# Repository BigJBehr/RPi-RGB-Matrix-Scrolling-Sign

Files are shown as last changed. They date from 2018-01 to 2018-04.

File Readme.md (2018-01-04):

# Raspberry Pi RGB LED Matrix Scrolling Sign
This project is for a Raspberry Pi based RGB LED Matrix scrolling sign. A python script running on the Raspberry Pi uses WiFi and your internet connection to collect data from various web sites. The collected data is parsed, formatted and display on the RGB Matrix as scrolling text messages. The sign scrolls; time, date, quote-of-the-day, jokes, local weather, environment data, headlines, birthday greetings and holiday messages. The birthday and holiday greetings are user definable by editing a pair of XML files. Complete instructions on how to build one of these is available on the Instructables web site here; https://www.instructables.com/id/Raspberry-Pi-Scrolling-Sign/.

This is a list of the files found here. All of these files should be in the same directory on your Raspberry Pi.
    RGB-32x64.py    - python script that runs the scrolling display
    options.ini     - configuration file that is used to enable/disable features
    birthdays.xml   - file of birthday messages and dates
    holidays.xml    - file of holiday messages and dates
    samplebase.py   - python script from the Henner Zeller RGB matrix library
    fonts           - fonts directory from the Henner Zeller RGB matrix drive library
    Eagle           - this folder contains the Eagle files required to make your own boards

The Henner Zeller RGB matrix library should also be in this directory. You can get the library here; https://github.com/hzeller/rpi-rgb-led-matrix

## The Eagle folder has a zip file that has what is needed to send to a board manufacturer to make boards for you. It also has the Eagle schematic and board layout files and a PDF of the schematic.

Enjoy

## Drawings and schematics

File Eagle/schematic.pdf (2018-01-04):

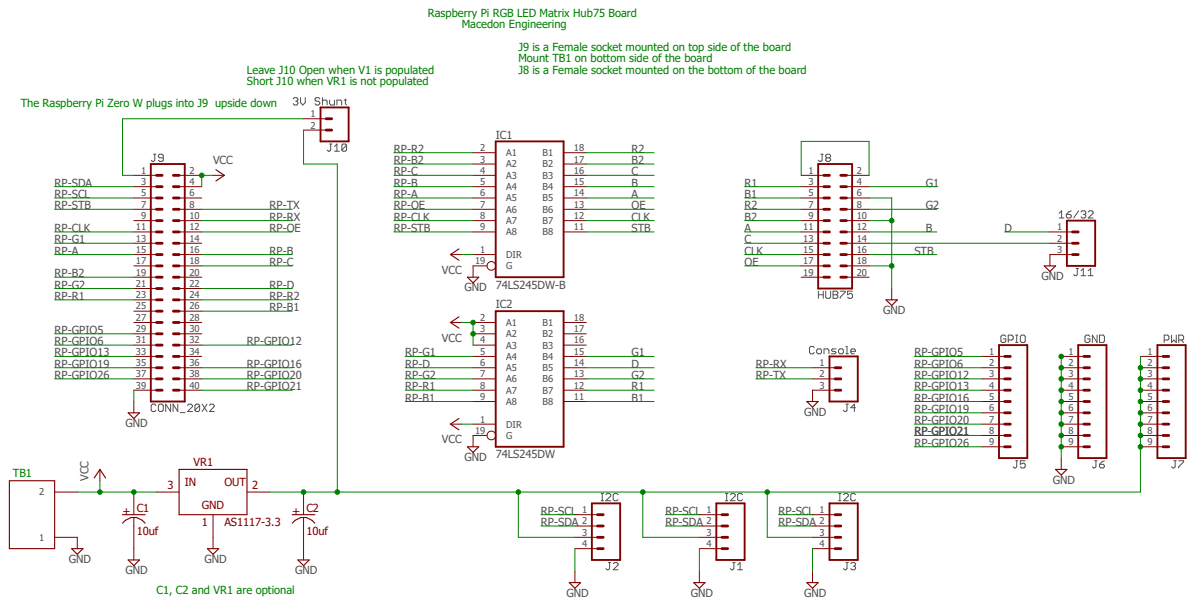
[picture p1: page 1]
GND; VCC; IC2DIR 1; IC1DIR 1; CLK; STB; RP-GPIO12; RP-GPIO16; RP-GPIO20; RP-GPIO21; RP-SDA; RP-SCL; RP-CLK; RP-STB; RP-GPIO5; RP-GPIO6; RP-GPIO13; RP-GPIO19; RP-GPIO26; OUT

Raspberry Pi RGB LED Matrix Hub75 Board
Macedon Engineering
VCC
RP-SDA
RP-SCL
RP-STB

J9 is a Female socket mounted on top side of the board
Mount TB1 on bottom side of the board
J8 is a Female socket mounted on the bottom of the board

Leave J10 Open when V1 is populated
Short J10 when VR1 is not populated

The Raspberry Pi Zero W plugs into J9 upside down

GND
C1, C2 and VR1 are optional

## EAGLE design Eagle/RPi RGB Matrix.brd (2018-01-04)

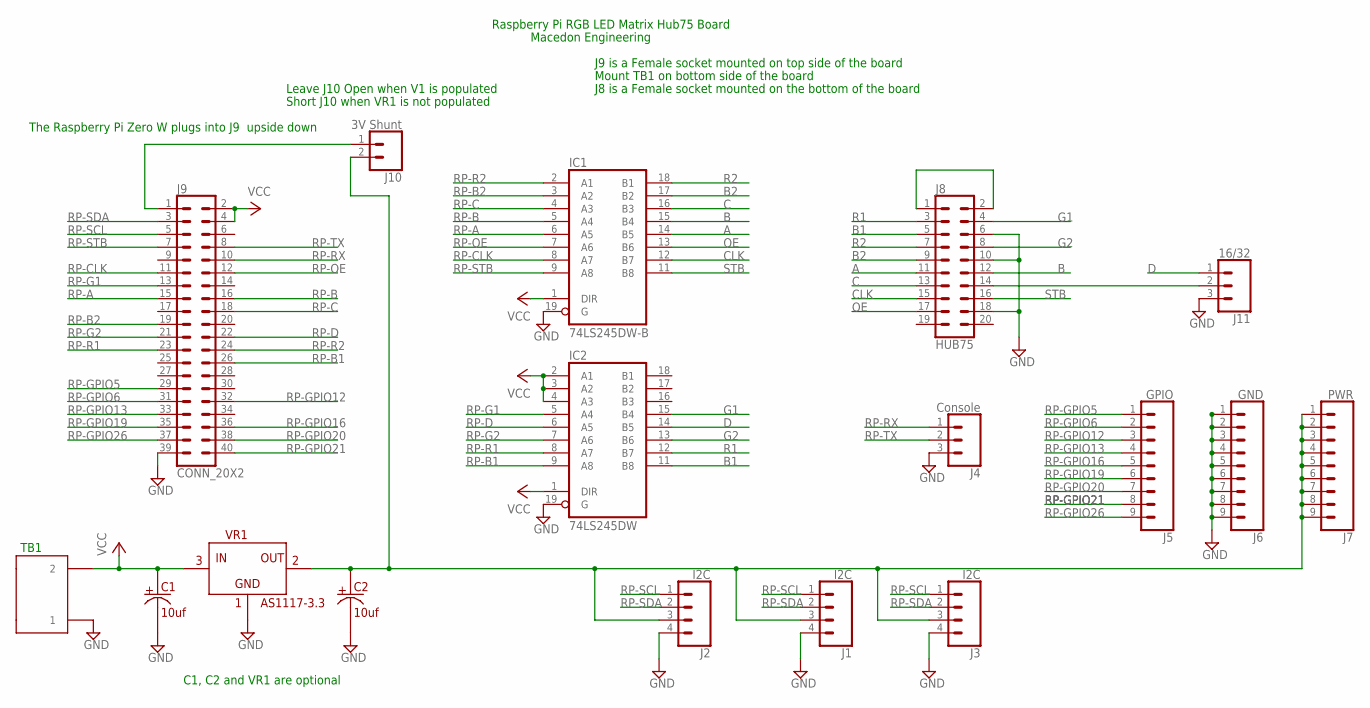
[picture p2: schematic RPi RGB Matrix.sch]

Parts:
C1, C2: 10uf; CAP-SMT-A
IC1: 74LS245DW-B; SO20W-B
IC2: 74LS245DW; SO20W
J1, J2, J3: I2C; 1X04
J4: Console; 1X03
J5: GPIO; 1X09
J6: GND; 1X09
J7: PWR; 1X09
J8: HUB75; 2X10
J9: CONN_20X2; 2X20
J10: 3V Shunt; 1X02
J11: 16/32; 1X03
TB1: TERMINALBLOCK-5MM-2POS
VR1: AS1117-3.3; SOT-223

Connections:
A: IC1.14 (B5), J8.11
B: IC1.15 (B4), J8.12
B1: IC2.11 (B8), J8.5
B2: IC1.17 (B2), J8.9
C: IC1.16 (B3), J8.13
CLK: IC1.12 (B7), J8.15
D: IC2.14 (B5), J11.1
G1: IC2.15 (B4), J8.4
G2: IC2.13 (B6), J8.8
GND: C1.P$2, C2.P$2, IC1.10 (GND), IC1.19 (G), IC2.10 (GND), IC2.19 (G), J1.4, J2.4, J3.4, J4.3, J6.1, J6.2, J6.3, J6.4, J6.5, J6.6, J6.7, J6.8, J6.9, J8.6, J8.10, J8.18, J9.39, J11.3, TB1.P$1 (1), TB1.P$4 (1), VR1.P$1
unnamed: J8.1, J8.2
unnamed: J9.1, J10.1
unnamed: C2.P$1, J1.3, J2.3, J3.3, J7.1, J7.2, J7.3, J7.4, J7.5, J7.6, J7.7, J7.8, J7.9, J10.2, VR1.P$2, VR1.P$4
unnamed: J8.14, J11.2
OE: IC1.13 (B6), J8.17
R1: IC2.12 (B7), J8.3
R2: IC1.18 (B1), J8.7
RP-A: IC1.6 (A5), J9.15
RP-B: IC1.5 (A4), J9.16
RP-B1: IC2.9 (A8), J9.26
RP-B2: IC1.3 (A2), J9.19
RP-C: IC1.4 (A3), J9.18
RP-CLK: IC1.8 (A7), J9.11
RP-D: IC2.6 (A5), J9.22
RP-G1: IC2.5 (A4), J9.13
RP-G2: IC2.7 (A6), J9.21
RP-GPIO5: J5.1, J9.29
RP-GPIO6: J5.2, J9.31
RP-GPIO12: J5.3, J9.32
RP-GPIO13: J5.4, J9.33
RP-GPIO16: J5.5, J9.36
RP-GPIO19: J5.6, J9.35
RP-GPIO20: J5.7, J9.38
RP-GPIO21: J5.8, J9.40
RP-GPIO26: J5.9, J9.37
RP-OE: IC1.7 (A6), J9.12
RP-R1: IC2.8 (A7), J9.23
RP-R2: IC1.2 (A1), J9.24
RP-RX: J4.1, J9.10
RP-SCL: J1.1, J2.1, J3.1, J9.5
RP-SDA: J1.2, J2.2, J3.2, J9.3
RP-STB: IC1.9 (A8), J9.7
RP-TX: J4.2, J9.8
STB: IC1.11 (B8), J8.16
VCC: C1.P$1, IC1.1 (DIR), IC1.20 (VCC), IC2.1 (DIR), IC2.2 (A1), IC2.3 (A2), IC2.4 (A3), IC2.20 (VCC), J9.2, J9.4, TB1.P$2 (2), TB1.P$3 (2), VR1.P$3

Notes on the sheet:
Raspberry Pi RGB LED Matrix Hub75 Board
Macedon Engineering
Mount TB1 on bottom side of the board
J9 is a Female socket mounted on top side of the board
J8 is a Female socket mounted on the bottom of the board
The Raspberry Pi Zero W plugs into J9 upside down
C1, C2 and VR1 are optional
Short J10 when VR1 is not populated
Leave J10 Open when V1 is populated
TB1

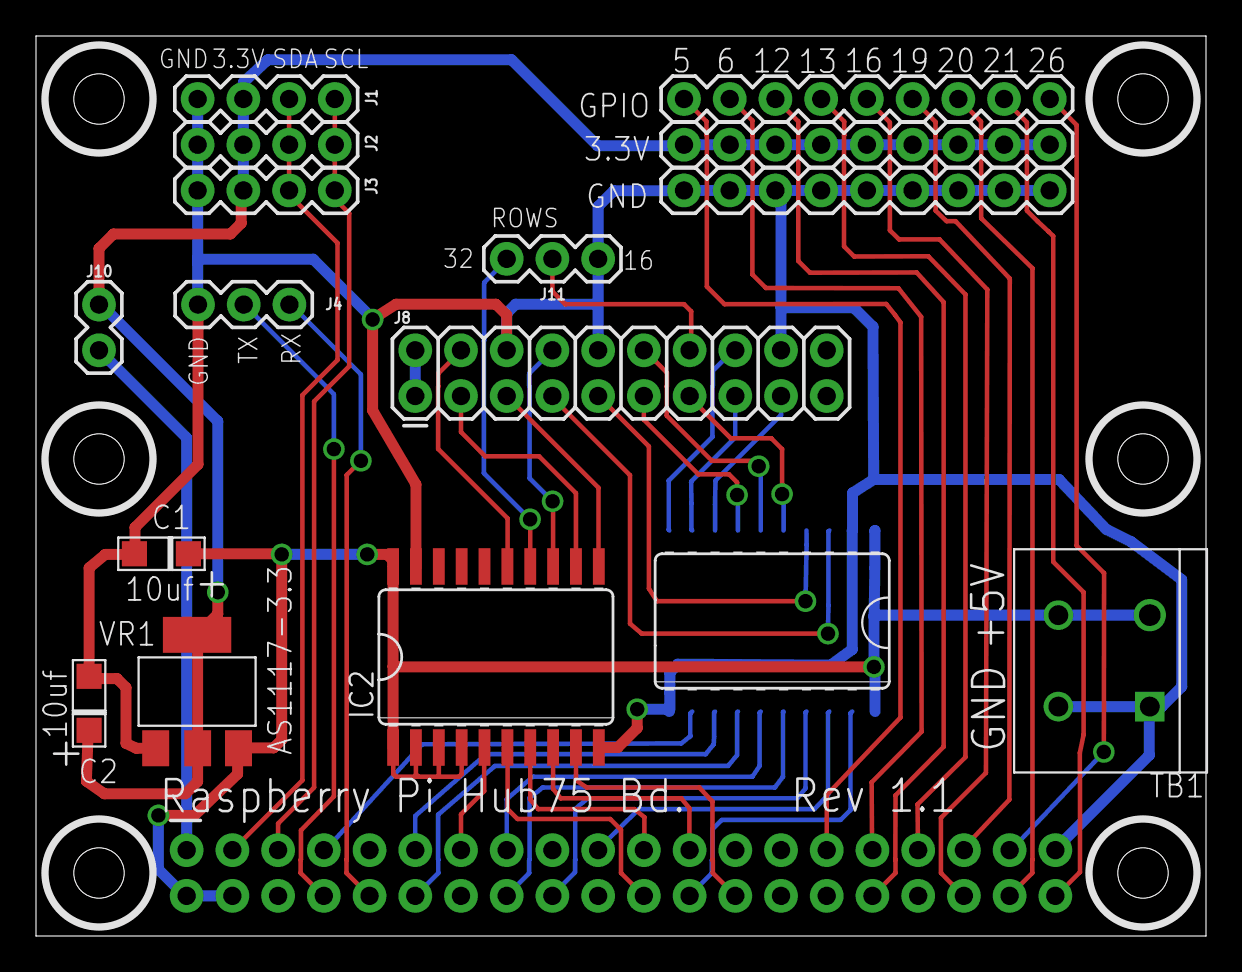
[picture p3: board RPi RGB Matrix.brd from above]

Board: 2 copper layers, 65.0 x 50.0 mm, 17 parts (1 on the bottom side), 45 nets.

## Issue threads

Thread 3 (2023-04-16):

Python 3.5+

dev03SS, 2023-04-16:
Getting a ton of syntax errors on my RPi 3B. Even simple print statements. Is there a new python file that should be used? Or is there an easy way to convert this to the newer versions of python?

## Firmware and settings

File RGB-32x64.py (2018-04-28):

#!/usr/bin/env python

# Author:  James R. Behrens
# Project: Rasperry Pi RGB 32x64 Scrolling display
# Target:  Stretch Lite running on a Raspberry Pi Zero W.

# This is a Python script that drives a 32x64 matrix of RGB LEDs. The RGB matrix
# panel uses a Hub75 interface.
# The Python script divides the 32x64 panel into two lines of text. Each line
# displays different information gathered from the Internet and from some local
# XML files. An INI file determines which features are enabled and provides the
# URLs for some of the Internet sites.
# A BME280 environmental sensor array provides in-house temperature, humidity
# and barometric pressure.

# The display is two 32x32 matrices on one board. Run with;
# sudo python RGB-32x64.py

# default matrix size in samplebase.py was changed to 32x64 from 32x32. This
# eliminated the need to add '-c 2' to the command line.'

# This script was adapted from one of the example programs that are included with
# the Henner Zeller LED-matrix library. The library is (c) Henner Zeller
# <h.zeller@acm.org>, licensed with GNU General Public License Version 2.0]
# (http://www.gnu.org/licenses/gpl-2.0.txt)(which means, if you use it in a
# product somewhere, you need to make the source and all your modifications
# available to the receiver of such product so that they have the freedom to
# adapt and improve). The driver library itself has not been modified. You can
# obtain the library from; https://github.com/hzeller/rpi-rgb-led-matrix.
# Read the README.md file. Follow the directions for installation and for
# eliminating interference from the 'snd_bcm2835' driver.

# this will prevent snd_bcm2835 driver from being loaded.
# the prompt should be similar to this; pi@StretchLite:~ $
# type; cat <<EOF | sudo tee /etc/modprobe.d/blacklist-rgb-matrix.conf
# the prompt will change to >
# type; blacklist snd_bcm2835
# type; EOF
# the prompt changes back to pi@StretchLite:~ $
# type; sudo update-initramfs -u

# reboot your Pi
# type; sudo reboot

# after the reboot
# type; lsmod
# look for snd_bcm2835. if it is present then try again. You should not see
# snd_bcm2835 when you type; lsmod


# This project uses the default, single display HUB75 interface wiring. Board
# layouts are provided with the library. AdaFruit has a compatible HAT.
# I created my own Raspberry Pi Hub75 interface board that breaks out the
# unused GPIO pins to a header. The I2C and console pins are also broken out
# to their own headers. Level shifters are incorporated for all pins that
# connect to the display. A jumper is provided for 16 or 32 row selection. An 
# optional 3.3V regulator was added to power any external addons.

# create a directory for this project
# mkdir /home/pi/rgb-32x64

# use WinSCP to copy the project files to the rgb-32x64 directory

# compile and install the Henner Zeller RGB LED Matrix library
# type; cd rpi-rgb-led-matrix-master/bindings/python
# type; sudo apt-get update && sudo apt-get install python2.7-dev python-pillow -y
# type; sudo make build-python
# type; sudo make install-python


# type; sudo python setup.py install
# type; cd ..
# type; cd ..
# type; cd ..

# All of the following must be in the same directory as 'RGB-32x64.py';
# 'fonts' directory, 'samplebase.py', 'birthdays.xml', 'holidays.xml' and
# 'options.ini'.
#
# This project needs some python libraries installed. At the Linux command
# prompt type the following commands to install the required libraries;

# Install pip. pip is used to install Python libraries.
# sudo apt-get install python-pip

# install smbus library
# type sudo apt-get install python-smbus

# install Python requests library
# type; sudo apt-get install python-requests


# To run on power up, edit /etc/rc.local to add the following two lines just
# above the 'exit 0' line;
# type; cd /home/pi/rgb-32x64
# type; sudo python RGB-32x64.py

# Change permissions of rc.local so you can edit it, type
# type; sudo chmod 777 /etc/rc.local

# rc.local should be executable. If not type;
# type sudo chmod +x /etc/rc.local

# to enable rc.local to run on startup
# type /etc/rc.local enable

# to disable /etc/rc.local from running on startup
# type /etc/rc.local disable

# message lists are lists of lists. each entry is a list with two values, text color
# and the text to display.

# changed to do one url at a time for headlines, like jokes does.

# Added weather forcasts. Made separate function for parsing weather data.

# BMP280 Temperature is reading about 5F too high. Modified to drop temperature
# by 5 degrees F.

# Apparently GitHub is stripping carriage returns out of the options.ini file.
# This is causing an Index Out of Range error when parsing the options.ini file.
# This is fixed in this version.

# Display a runtext with double-buffering.
import datetime
import time
import thread
import threading
import calendar
import decimal
import os.path
import json
import requests
import htmlentitydefs
import gc
import sys
import socket
import struct
import string
import random

from HTMLParser import HTMLParser
from xml.dom import minidom
from socket import AF_INET, SOCK_DGRAM
from samplebase import SampleBase
from rgbmatrix import graphics
from smbus import SMBus

# sensor data variables
lastPressure = 0
barometer    = [0.0, 0.0, 0.0]

# create an SMBUS (I2C) object, use bus 1, bus 0 is reserved
Bme = SMBus(1)
  
lastDow       = 0

# dirtyFlag is used to indicate when a new bottomList needs to be built
dirtyFlag     = True

# dirtyLock is used to prevent multiple threads from accessing various lists
# at the same time. simple thread protectiom mechanism
dirtyLock     = threading.Lock()

topIndex      = 0
bottomIndex   = 0

jokesIndex    = 0

topList     = []
bottomList  = []

# using separate lists makes it easier to update sensor & weather messages
# without having to re-build other lists
sensorList  = []
dailyList   = []
weatherList = []
quoteList   = []
jokeList    = []
newsList    = []

##### options, these are read in from the options.ini file on startup #####
militaryTime = False

#..BME280 sensor enables
temperature  = True
humidity     = True
pressure     = True

weatherEnabled = False
weatherKey     = ''
weatherZip     = ''

quoteEnabled = False
quoteUrl     = ''

jokesEnabled = False
jokesUrls    = []
jokesDelay   = 3600

newsEnabled  = False
newsUrls     = []


# bottom row of font. leave two below for decenders
Row1 = 11
Row2 = 28

#===== BME280 Calibration Data Storage =====
digT1 = 0     # temperature compensation data
digT2 = 0
digT3 = 0

digP1 = 0    # humidity compensation data
digP2 = 0
digP3 = 0
digP4 = 0
digP5 = 0
digP6 = 0
digP7 = 0
digP8 = 0
digP9 = 0

digH1 = 0    # pressure compensation data
digH2 = 0
digH3 = 0
digH4 = 0
digH5 = 0
digH6 = 0

#===== BME280 Register names, do not modify =====
BME280_DIG_T1_LSB_REG =	0x88
BME280_DIG_T1_MSB_REG =	0x89
BME280_DIG_T2_LSB_REG =	0x8A
BME280_DIG_T2_MSB_REG =	0x8B
BME280_DIG_T3_LSB_REG =	0x8C
BME280_DIG_T3_MSB_REG =	0x8D
BME280_DIG_P1_LSB_REG =	0x8E
BME280_DIG_P1_MSB_REG =	0x8F
BME280_DIG_P2_LSB_REG =	0x90
BME280_DIG_P2_MSB_REG =	0x91
BME280_DIG_P3_LSB_REG =	0x92
BME280_DIG_P3_MSB_REG =	0x93
BME280_DIG_P4_LSB_REG =	0x94
BME280_DIG_P4_MSB_REG =	0x95
BME280_DIG_P5_LSB_REG =	0x96
BME280_DIG_P5_MSB_REG =	0x97
BME280_DIG_P6_LSB_REG =	0x98
BME280_DIG_P6_MSB_REG =	0x99
BME280_DIG_P7_LSB_REG =	0x9A
BME280_DIG_P7_MSB_REG =	0x9B
BME280_DIG_P8_LSB_REG =	0x9C
BME280_DIG_P8_MSB_REG =	0x9D
BME280_DIG_P9_LSB_REG =	0x9E
BME280_DIG_P9_MSB_REG =	0x9F
BME280_DIG_H1_REG           =	0xA1
BME280_CHIP_ID_REG          =	0xD0 # Chip ID
BME280_RST_REG              =	0xE0 # Softreset Reg
BME280_DIG_H2_LSB_REG       =	0xE1
BME280_DIG_H2_MSB_REG       =	0xE2
BME280_DIG_H3_REG           =	0xE3
BME280_DIG_H4_MSB_REG       =	0xE4
BME280_DIG_H4_LSB_REG       =	0xE5
BME280_DIG_H5_MSB_REG       =	0xE6
BME280_DIG_H6_REG           =	0xE7
BME280_CTRL_HUMIDITY_REG    =	0xF2 # Ctrl Humidity Reg
BME280_STAT_REG             =	0xF3 # Status Reg
BME280_CTRL_MEAS_REG        =	0xF4 # Ctrl Measure Reg
BME280_CONFIG_REG           =	0xF5 # Configuration Reg
BME280_PRESSURE_MSB_REG     =	0xF7 # Pressure MSB
BME280_PRESSURE_LSB_REG     =	0xF8 # Pressure LSB
BME280_PRESSURE_XLSB_REG    = 0xF9 # Pressure XLSB
BME280_TEMPERATURE_MSB_REG  = 0xFA # Temperature MSB
BME280_TEMPERATURE_LSB_REG  = 0xFB # Temperature LSB
BME280_TEMPERATURE_XLSB_REG =	0xFC # Temperature XLSB
BME280_HUMIDITY_MSB_REG     =	0xFD # Humidity MSB
BME280_HUMIDITY_LSB_REG     =	0xFE # Humidity LSB

BMEADRS =	0x76        # I2C address of the BME280
BME280_CHIP_ID = 0x60 # chip ID of the BME280

UNSIGNED = 0
SIGNED = 1


#==============================================================================
# return True if the string afer '=' starts with 't' or 'T' otherwise return
# false
def truefalse(str):
  s = 't'         # default to true
  if len(str) > 0:
    s = str[0].lower()
    
  return 't' == s
    
#==============================================================================
# Read the options file into memory. Options 
# read options.ini into global vars
def readOptions(filename):
  global military

  global temperature
  global humidity
  global pressure

  global weatherEnabled
  global weatherKey
  global weatherZip
  
  global quoteEnabled
  global quoteUrl
  
  global jokesEnabled
  global jokesUrls
  global jokesDelay

  global newsEnabled
  global newsUrls
    
  if os.path.isfile(filename):
    try:
      with open(filename, 'r') as f:
        print "Reading options file"
        for line in f:
          if len(line) > 2:
            # split on the first '=' only
            s = line[:len(line) - 1].split('=', 1)
            value = s[1][:len(s[1])]
            
            if s[0] == 'military':
              military = truefalse(value)
            elif s[0] == 'temperature':
              temperature = truefalse(value)
            elif s[0] == 'humidity':
              humidity = truefalse(value)
            elif s[0] == 'pressure':
              pressure = truefalse(value)
            elif s[0] == 'weather':
              weatherEnabled = truefalse(value)
            elif s[0] == 'weatherkey':
              weatherKey = value
            elif s[0] == 'weatherzip':
              weatherZip = value
            elif s[0] == 'quote':
              quoteEnabled = truefalse(value)
            elif s[0] == 'quoteurl':
              # we may have a list of urls to get jokes from
              quoteUrl = value
            elif s[0] == 'jokes':
              jokesEnabled = truefalse(value)
            elif s[0] == 'jokesurl':
              # there are multiple joke URLs. each for a differnt type of joke
              jokesUrls.append(value)
            elif s[0] == 'jokedelay':
              jokesDelay = int(value)
            elif s[0] == 'news':
              newsEnabled = truefalse(value)
            elif s[0] == 'newsurl':
              # there may be multiple news feeds used
              # there maybe multiple '=' in the url
              newsUrls.append(value)
    except IOError:
      print "Failure reading options file"
    except IndexError:
      print "Error in options.ini: " + line
  else:
    print "Unable to find options.ini file"
                        
#==============================================================================
# Create a random color
def randomColor():
  min = 64      # higher numbers yield brighter colors, max is 255
  max = 255     # low numbers yield dimmer colors.
  
  r = random.randint(min, max)
  g = random.randint(min, max)
  b = random.randint(min, max)
  return graphics.Color(r, g, b)

#==============================================================================
# get the current Internet time from an NTP server
def getNTPTime(host = "pool.ntp.org"):
  port = 123
  buf = 1024
  address = (host, port)
  msg = '\x1b' + 47 * '\0'
  
  # reference time (in seconds since 1900-01-01 00:00:00)
  TIME1970 = 2208988800L # 1970-01-01 00:00:00
  
  # connect to server
  client = socket.socket(AF_INET, SOCK_DGRAM)
  client.sendto(msg, address)
  msg, address = client.recvfrom(buf)
  
  t = struct.unpack("!12I", msg)[10]
  t -= TIME1970
  return time.ctime(t).replace("  "," ")
  
#==============================================================================
# create a date message
# this is run while the dirtyLock has been acquired, so safe to change dailyList
# xml files must be in same directory as executable

def dateMessage():
  global lastDow
     
  dow = datetime.datetime.today()
  dayname = calendar.day_name[dow.weekday()]
  text = dayname + ", " + datetime.datetime.now().strftime("%b %d %Y")

  # check for change of dow, signals new day
  if lastDow != dow.weekday():
    print 'New Day' + str(dow.weekday()) + ', ' + str(lastDow)
    del dailyList[:]
    loadFromXml("holidays.xml",  str(datetime.datetime.now().month), str(datetime.datetime.now().day), dayname)
    loadFromXml("birthdays.xml", str(datetime.datetime.now().month), str(datetime.datetime.now().day), dayname)
  
  lastDow = dow.weekday()
  return text

#==============================================================================
# create time msg
# this is run while the dirtyLock has been acquired

def timeMessage():
  global military
  
  if military == False:
    h = datetime.datetime.now().hour
    if h > 12:
      h -= 12
        
    if 0 == h:
      h = 12

    text = '{:2d}:{:02d}:{:02d}'.format(h, datetime.datetime.now().minute, datetime.datetime.now().second)
  else:
    text = datetime.datetime.now().strftime("%H:%M")

  return text
             
#==============================================================================
# Class to strip HTML tags from strings.

class HTMLTextExtractor(HTMLParser):
  def __init__(self):
    HTMLParser.__init__(self)
    self.result = [ ]

  def handle_data(self, d):
    self.result.append(d)

  def handle_charref(self, number):
    codepoint = int(number[1:], 16) if number[0] in (u'x', u'X') else int(number)
    self.result.append(unichr(codepoint))

  def handle_entityref(self, name):
    codepoint = htmlentitydefs.name2codepoint[name]
    self.result.append(unichr(codepoint))

  def get_text(self):
     return u''.join(self.result)

#==============================================================================
# Remove HTML tags from a string.
def html_to_text(html):
  s = HTMLTextExtractor()
  s.feed(html)
  return s.get_text()
    
#==============================================================================
# Get a joke from the Internet. Parse out the joke and author. There may be
# multiple joke URLs. Use a different URL each time this is invoked.
def getAJoke():
  global jokeList
  global jokeUrls
  global dirtyFlag
  global jokesIndex
  global jokesDelay
  
  list   = []  
  while True:
    # try to get a new joke
    try:
      r = requests.get(jokesUrls[jokesIndex])
    except:
      print 'Jokes, invalid URL: {}'.format(jokesUrls[jokesIndex])
    finally:
      if 200 == r.status_code:
        # parse the joke from the HTML pages. the parsed text is combined into
        # one long string and then broken down into displayable pieces.
  
        flag   = 0
        joke   = ''
        author = ''
  
        color = randomColor()             
        # split the HTML into lines
        lines = r.text.splitlines()
       
        for line in lines:
          if 0 == flag:
            if '<P>' == line:
              flag = 1

          elif 1 == flag:
            if '<CENTER>' == line:
              flag = 2

 # this caused an issue when non-joke text was processed. contained non-ascii 
 # characters             
            else:
              # strip HTML. convert to ASCII and remove all leading and trailing
              # whitespace
              line1 = html_to_text(line).strip().encode('ascii')
              if len(line1) > 0:
                # remove spaces and dashes
                line1 = line1.strip('- ')
                joke += ' ' + line1
                if joke.endswith('?') or joke.endswith('.'):
                  list.append([color, joke])
                  joke = ''
        # for
        
        # we found a joke.
        if len(joke) > 0:
          list.append([color, joke])

        if len(list) > 0:
          dirtyLock.acquire()
          del jokeList[:]
          dirtyFlag = True
          jokeList += list
          dirtyLock.release()
          del list[:]
        else:
          print 'No joke from: ' + jokesUrls[jokesIndex]
          
        # we may have several joke URLs. step through them one at a time.
        jokesIndex += 1
        if jokesIndex == len(jokesUrls):
          jokesIndex = 0
  
      else:
        print 'Get a Joke Failed to connect'

      
    # sleep for some number of seconds
    time.sleep(jokesDelay)
  # while    
        
#==============================================================================
# Get the Quote-of-the-day. Parse out the quote and author. Add it to the 
# quoteList.
def getQuoteOfTheDay():
  global quoteList
  global dirtyFlag
  
  quote = []
  ql = []
  delay = 3600        # update once an hour
  while True:
    try:
      print 'QOD Thread'
      r = requests.get(quoteUrl, auth=('user', 'pass'))
      if 200 == r.status_code:
#        print '===== QOD ====='
#        print r.text
#        print '====='
        # split into individual lines
        list = r.text.splitlines()
              
        for l in list:
#          print l
          # only interested in lines that start with 'br.writeln'
          if l.startswith('br.writeln'):
            # strip off the first 12 characters
            s = l[12:]
            # nothing of interest starts with '<b'
            if not s.startswith('<b'):
              # parse the quote. quote ends with '<br>'
              if s.endswith('<br>");'):
                quote.append(s[:s.find('<br>')])
              
              # parse the author.
              pos = s.find('</a>')
              if pos > 0:
                quote.append(s[s.find('>') + 1:pos])
  
        if len(quote) > 0:
          color = randomColor()
          if len(quote[0]) > 0:
            ql.append([color, cleanupUnicode(quote[0])])
    
            # add the author
            if len(quote[1]) > 0:
              ql.append([color, cleanupUnicode(quote[1])])
          else:
            # no quote given
            print 'No quote found'
        else:
          # no quote given
          print 'No quote found'
            
      else:
        print 'Quote of the Day returned an error: ' + str(r.status_code)
  
    except:
      print "Quote of the day failed to connect"
      
      # use default quote
      color = randomColor()
      ql.append([color, 'Progress is impossible without change, and those who cannot change their minds cannot change anything'])
      ql.append([color, 'George Bernard Shaw'])
    # try/except
        
    dirtyLock.acquire()
    del quoteList[:]
    dirtyFlag = True
    print 'Quote of the Day'
    quoteList += ql
    dirtyLock.release()
    del ql[:]
    del quote[:]
    
    # sleep for some number of seconds
    time.sleep(delay)
  # while
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

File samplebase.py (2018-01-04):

import argparse
import time
import sys
import os

sys.path.append(os.path.abspath(os.path.dirname(__file__) + '/..'))
from rgbmatrix import RGBMatrix, RGBMatrixOptions


class SampleBase(object):
    def __init__(self, *args, **kwargs):
        self.parser = argparse.ArgumentParser()

        self.parser.add_argument("-r", "--led-rows", action="store", help="Display rows. 16 for 16x32, 32 for 32x32. Default: 32", default=32, type=int)
        self.parser.add_argument("-c", "--led-chain", action="store", help="Daisy-chained boards. Default: 2.", default=2, type=int)
        self.parser.add_argument("-P", "--led-parallel", action="store", help="For Plus-models or RPi2: parallel chains. 1..3. Default: 1", default=1, type=int)
        self.parser.add_argument("-p", "--led-pwm-bits", action="store", help="Bits used for PWM. Something between 1..11. Default: 11", default=11, type=int)
        self.parser.add_argument("-b", "--led-brightness", action="store", help="Sets brightness level. Default: 100. Range: 1..100", default=100, type=int)
        self.parser.add_argument("-m", "--led-gpio-mapping", help="Hardware Mapping: regular, adafruit-hat, adafruit-hat-pwm" , choices=['regular', 'adafruit-hat', 'adafruit-hat-pwm'], type=str)
        self.parser.add_argument("--led-scan-mode", action="store", help="Progressive or interlaced scan. 0 Progressive, 1 Interlaced (default)", default=1, choices=range(2), type=int)
        self.parser.add_argument("--led-pwm-lsb-nanoseconds", action="store", help="Base time-unit for the on-time in the lowest significant bit in nanoseconds. Default: 130", default=130, type=int)
        self.parser.add_argument("--led-show-refresh", action="store_true", help="Shows the current refresh rate of the LED panel")
        self.parser.add_argument("--led-slowdown-gpio", action="store", help="Slow down writing to GPIO. Range: 1..100. Default: 1", choices=range(3), type=int)
        self.parser.add_argument("--led-no-hardware-pulse", action="store", help="Don't use hardware pin-pulse generation")


    def usleep(self, value):
        time.sleep(value / 1000000.0)

    def run(self):
        print("Running")

    def process(self):
        self.args = self.parser.parse_args()

        options = RGBMatrixOptions()

        if self.args.led_gpio_mapping != None:
          options.hardware_mapping = self.args.led_gpio_mapping
        options.rows = self.args.led_rows
        options.chain_length = self.args.led_chain
        options.parallel = self.args.led_parallel
        options.pwm_bits = self.args.led_pwm_bits
        options.brightness = self.args.led_brightness
        options.pwm_lsb_nanoseconds = self.args.led_pwm_lsb_nanoseconds
        if self.args.led_show_refresh:
          options.show_refresh_rate = 1

        if self.args.led_slowdown_gpio != None:
            options.gpio_slowdown = self.args.led_slowdown_gpio
        if self.args.led_no_hardware_pulse:
          options.disable_hardware_pulsing = True

        self.matrix = RGBMatrix(options = options)

        try:
            # Start loop
            print("Press CTRL-C to stop sample")
            self.run()
        except KeyboardInterrupt:
            print("Exiting\n")
            sys.exit(0)

        return True

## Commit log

2018-01-04 Added link to Instructables site, added text about Eagle files
    Added link to Instructables site, added text about Eagle files
    [RPi RGB Matrix.brd, RPi RGB Matrix.sch]
2018-04-28 Fixed issue with options.ini
    Fixed readOptions() to properly parsed files with carriage returns stripped out.
    Fixed timeMessage() to create time messages in military (24 hour) format.
    Renamed RGB-32x64 .py with RGB-32x64.py
    [RGB-32x64.py]

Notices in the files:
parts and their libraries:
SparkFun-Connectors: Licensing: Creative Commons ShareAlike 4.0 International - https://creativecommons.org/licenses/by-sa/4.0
